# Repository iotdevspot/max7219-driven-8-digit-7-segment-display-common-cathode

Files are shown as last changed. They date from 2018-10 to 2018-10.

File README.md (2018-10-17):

# max7219-driven-8-digit-7-segment-display-common-cathode
This is my first PCB that got manufactured A display driver module with Maxim's MAX7219CNG IC and two four digit seven segment displays. The design was made with Eagle and it was manufactured by JLCPCB.

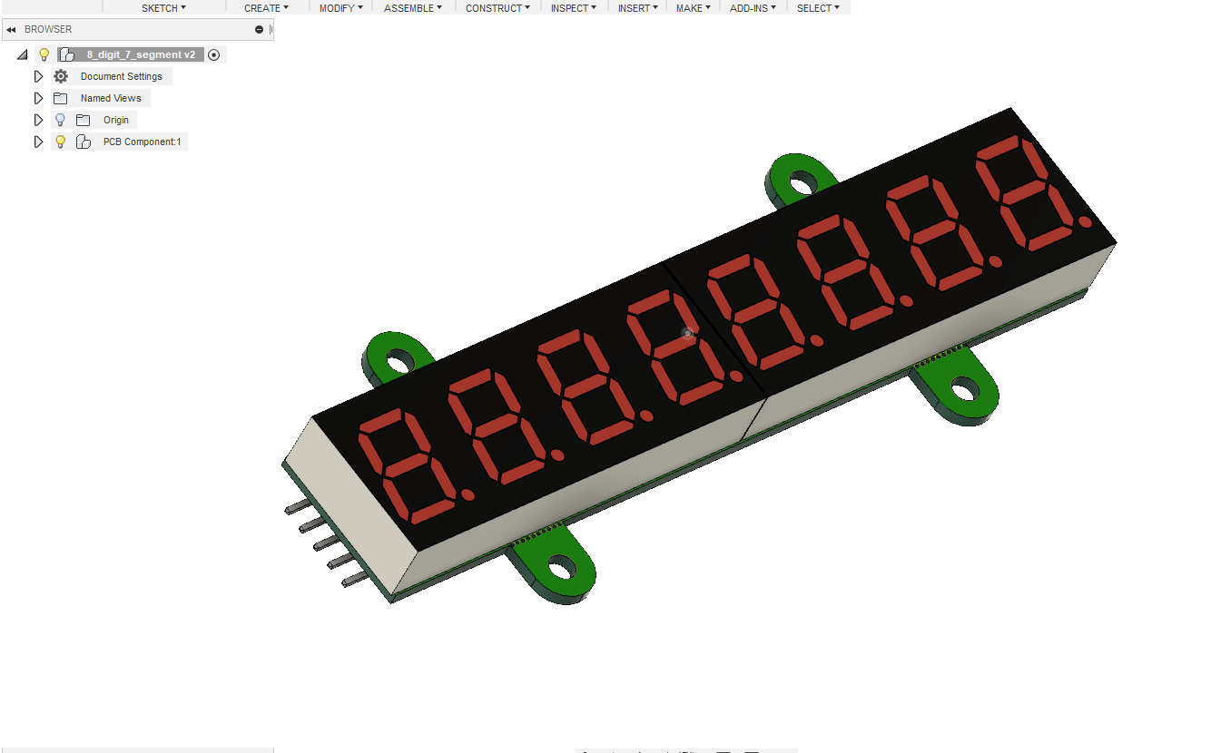
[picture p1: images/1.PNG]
Fusion360 model


The repository contains Arduino example codes, images of the PCBs and of the assembled module, Eagle schematic and board layout and gerber files. Some of the components are still missing from the 3D model so it's unavailable yet, but I'll upload to my Fusion360 [gallery](https://gallery.autodesk.com/fusion360/users/S2YAKSQZSPKT) as it's ready.

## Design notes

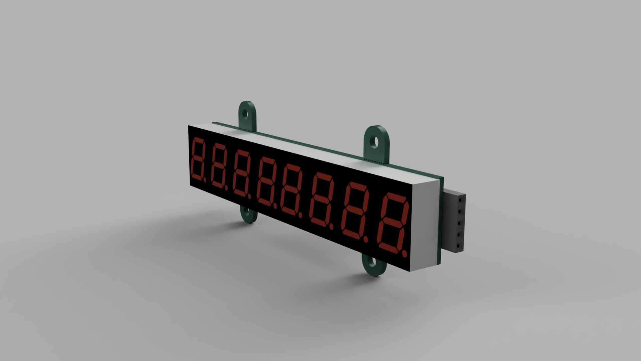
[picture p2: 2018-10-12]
images/8_digit_7_segment_2018-Oct-09_06-47-52PM-000_CustomizedView6771512328.png

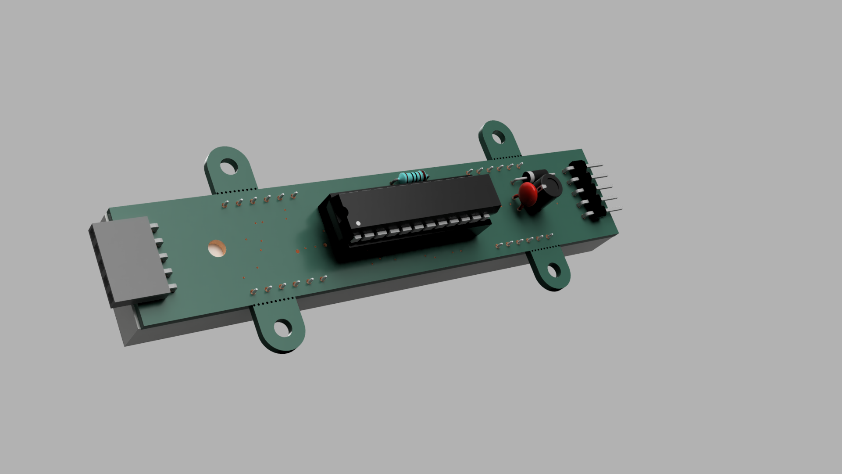
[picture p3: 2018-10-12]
images/8_digit_7_segment_2018-Oct-09_06-48-20PM-000_CustomizedView1024312791.png

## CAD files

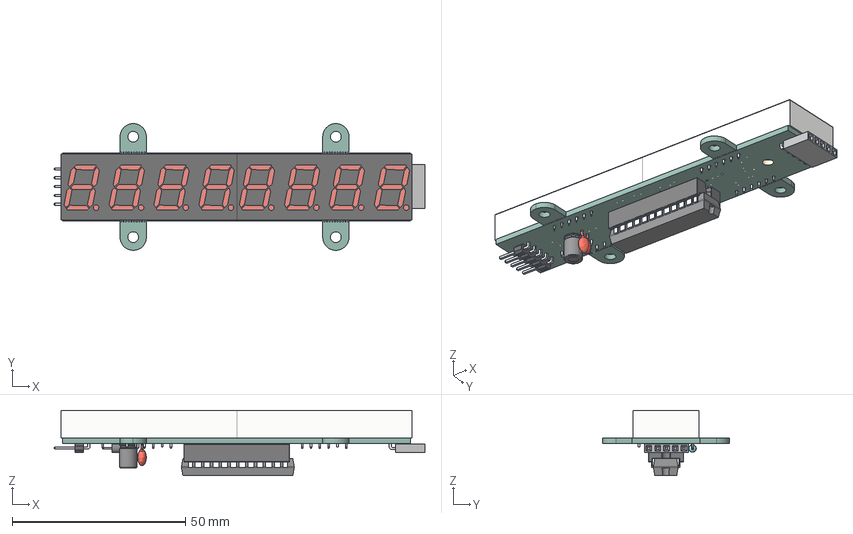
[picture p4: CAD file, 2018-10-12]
8_digit_7_segment v7.step
107.0 x 36.5 x 18.9 mm
Board
ATA8041ARBJ x 2
1X05/90
1leg v2 x 5
1N4148DO35-10
10k
10uF
The Basic 3dModel (32) v1
100nF

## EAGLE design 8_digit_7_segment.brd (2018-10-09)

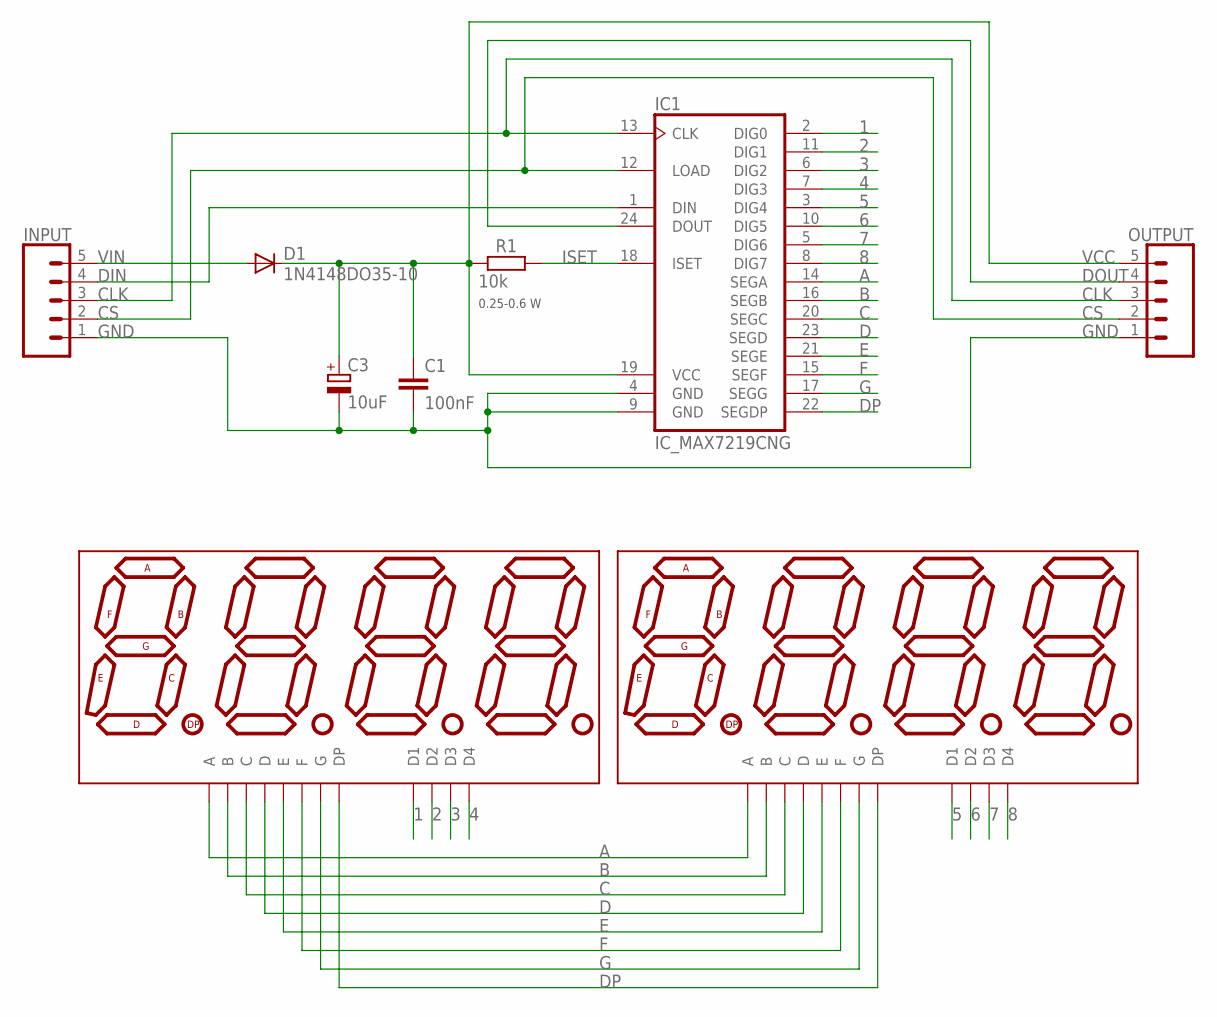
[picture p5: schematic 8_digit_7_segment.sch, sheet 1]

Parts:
C1: 100nF; C025-024X044
C3: 10uF; E2-5
D1: 1N4148DO35-10; D-10
DISP5, DISP6: ATA8041ARBJ; 7-SEGMENT-4DIGIT-20MM
IC1: IC_MAX7219CNG; DIL24-3
INPUT: CONN_051X05LA; 1X05/90
OUTPUT: CONN_051X05/90_FEMALE; 1X05/90FEMALE
R1: 10k; 0207/7

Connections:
1: DISP5.12 (D1), IC1.2 (DIG0)
2: DISP5.9 (D2), IC1.11 (DIG1)
3: DISP5.8 (D3), IC1.6 (DIG2)
4: DISP5.6 (D4), IC1.7 (DIG3)
5: DISP6.12 (D1), IC1.3 (DIG4)
6: DISP6.9 (D2), IC1.10 (DIG5)
7: DISP6.8 (D3), IC1.5 (DIG6)
8: DISP6.6 (D4), IC1.8 (DIG7)
A: DISP5.11 (A), DISP6.11 (A), IC1.14 (SEGA)
B: DISP5.7 (B), DISP6.7 (B), IC1.16 (SEGB)
C: DISP5.4 (C), DISP6.4 (C), IC1.20 (SEGC)
CLK: IC1.13 (CLK), INPUT.3, OUTPUT.3
CS: IC1.12 (LOAD), INPUT.2, OUTPUT.2
D: DISP5.2 (D), DISP6.2 (D), IC1.23 (SEGD)
DIN: IC1.1 (DIN), INPUT.4
DOUT: IC1.24 (DOUT), OUTPUT.4
DP: DISP5.3 (DP), DISP6.3 (DP), IC1.22 (SEGDP)
E: DISP5.1 (E), DISP6.1 (E), IC1.21 (SEGE)
F: DISP5.10 (F), DISP6.10 (F), IC1.15 (SEGF)
G: DISP5.5 (G), DISP6.5 (G), IC1.17 (SEGG)
GND: C1.2, C3.-, IC1.4 (GND), IC1.9 (GND), INPUT.1, OUTPUT.1
ISET: IC1.18 (ISET), R1.2
VCC: C1.1, C3.+, D1.C, IC1.19 (VCC), OUTPUT.5, R1.1
VIN: D1.A, INPUT.5

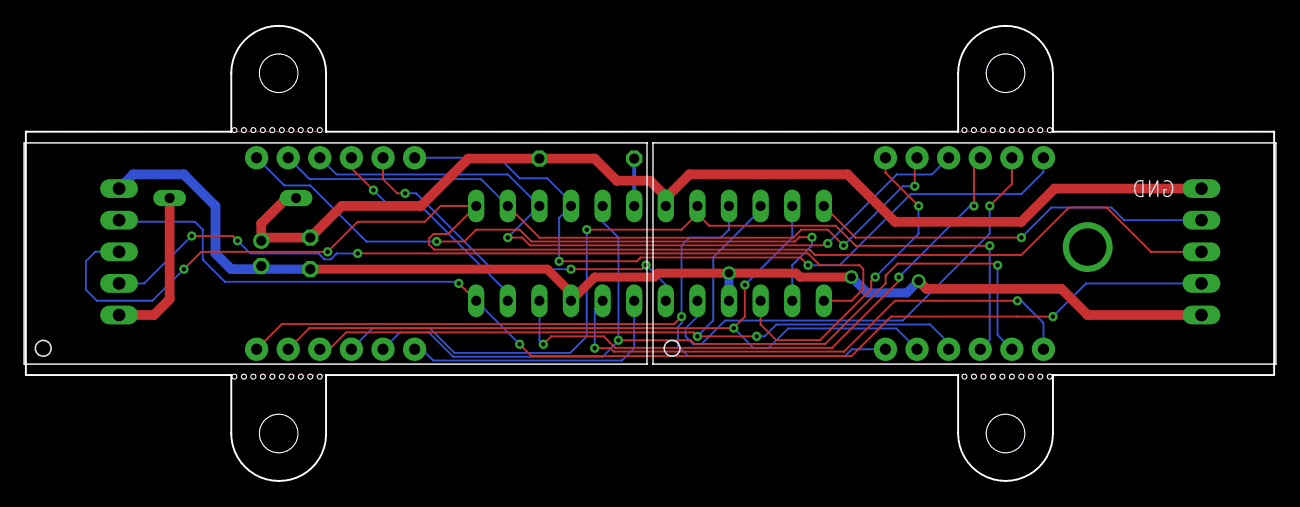
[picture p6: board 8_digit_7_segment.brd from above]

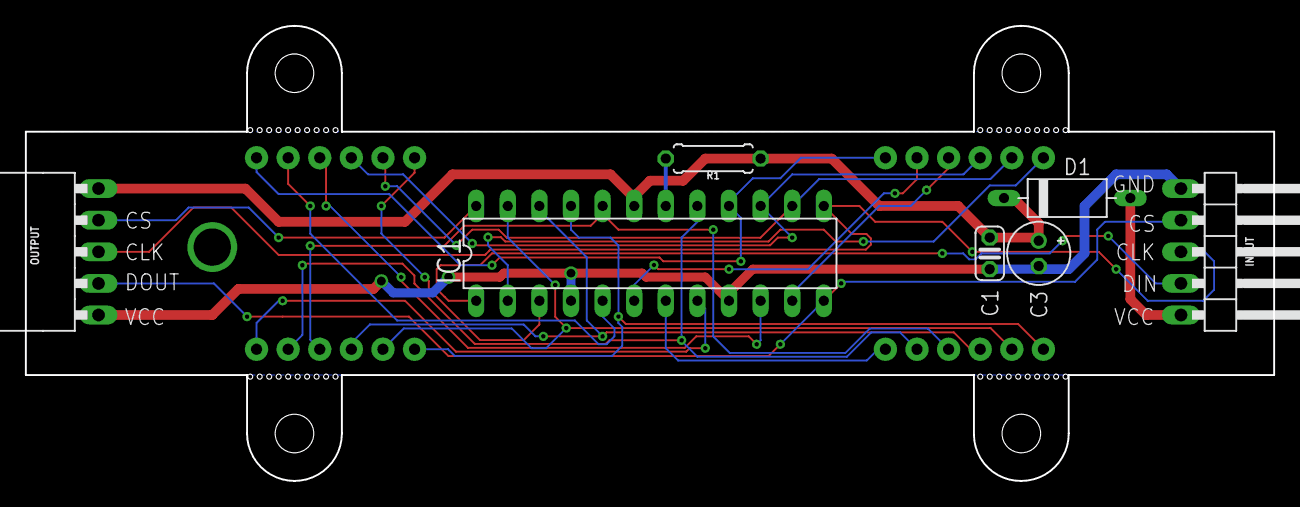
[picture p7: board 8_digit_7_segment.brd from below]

Board: 2 copper layers, 100.3 x 36.6 mm, 9 parts (7 on the bottom side), 24 nets.

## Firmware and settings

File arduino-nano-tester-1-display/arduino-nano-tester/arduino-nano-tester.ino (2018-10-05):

// Source code is from: http://embedded-lab.com/blog/introducing-a-new-serial-spi-8-digit-seven-segment-led-display-module-using-max7219/

#include "LedControl.h"
// Arduino Pin 7 to DIN, 6 to Clk, 5 to LOAD, no.of devices is 1
LedControl lc=LedControl(7,6,5,1);
void setup()
{
 // Initialize the MAX7219 device
  lc.shutdown(0,false);   // Enable display
  lc.setIntensity(0,15);  // Set brightness level (0 is min, 15 is max)
  lc.clearDisplay(0);     // Clear display register
}
void loop()
{
  for(int i=0; i < 8; i++){
   lc.setDigit(0,i,i+1,false); // Decimal point disabled
  }  
  delay(3000);
}

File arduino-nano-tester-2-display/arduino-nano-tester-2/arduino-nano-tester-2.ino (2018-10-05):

// Source code is from: http://embedded-lab.com/blog/introducing-a-new-serial-spi-8-digit-seven-segment-led-display-module-using-max7219/

#include "LedControl.h"
// Pin 7 to Data In, 6 to Clk, 5 to LOAD, number of devices is 3
LedControl lc=LedControl(7,6,5,2);
void setup()
{
  // Initialize the 2 MAX7219 devices
  for(int k=0; k<2; k++){
    lc.shutdown(k,false);  // Enable display
    lc.setIntensity(k,15); // Set brightness level (0 is min, 15 is max)
    lc.clearDisplay(k);    // Clear display register
  }
}
void loop()
{
  int count = 0;
  for(int j=0; j<2; j++){
    for(int i=0; i<8; i++){
     lc.setDigit(j,i,count, false);  // Decimal point disabled
     count++;
     if(count == 16)
      count=0;
    }  
    delay(1000);
  }
}

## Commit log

2018-10-05 Eagle files and two arduino test sketch added
    [8_digit_7_segment.brd, 8_digit_7_segment.sch]
2018-10-09 Minor modifications, 3D components added to the Eagle files and new images added of the 3D model
    [8_digit_7_segment.brd, 8_digit_7_segment.sch]
2018-10-12 STEP file (3D model of the module) and slight modification after manufacturing
    [8_digit_7_segment v7.step]
